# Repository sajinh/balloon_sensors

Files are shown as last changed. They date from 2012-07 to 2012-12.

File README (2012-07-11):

On the balloon we aim for data logging instead of real-time transmission. The
balloon is to be brought down periodically to collect data. Data is collected
using an onboard uLog.

We use BMP085 to measure absolute pressure. This also provides the temperature
value. BMP085 uses a Two Wire protocol for data transmission and operates
at 3.3V.  Analog Pin 5 is used for SCL and Analog Pin 4 for SDA.

We use HH10D to measure relative humidity. A Two Wire interface is needed
to read calibration coefficients from its onboard EEPROM. However we 
read it for once, record it in the sensor code, and never use the Two Wire
interface thereafter. The data is output as encoded frequency and output through
the middle pin.

uLog is a Serial Logger. Data is send through the TX line of the microcontroller

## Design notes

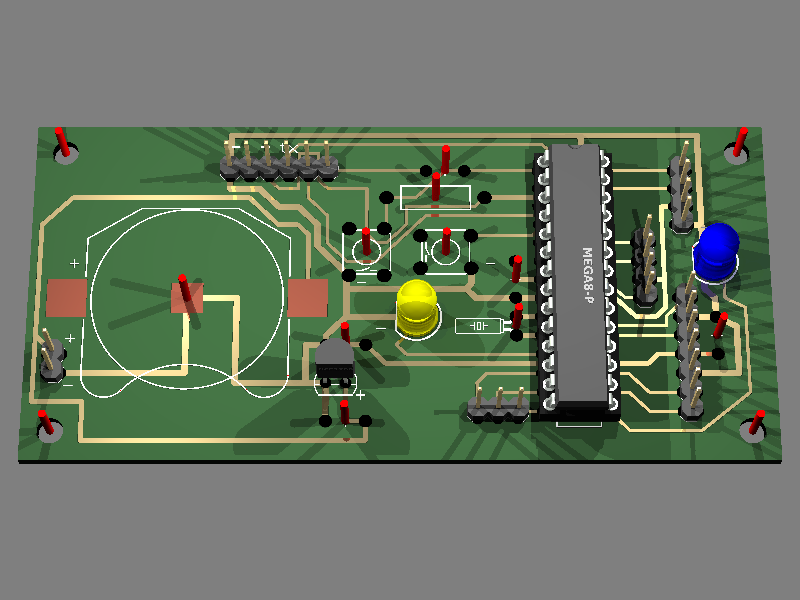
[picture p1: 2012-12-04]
Eagle/controller.png

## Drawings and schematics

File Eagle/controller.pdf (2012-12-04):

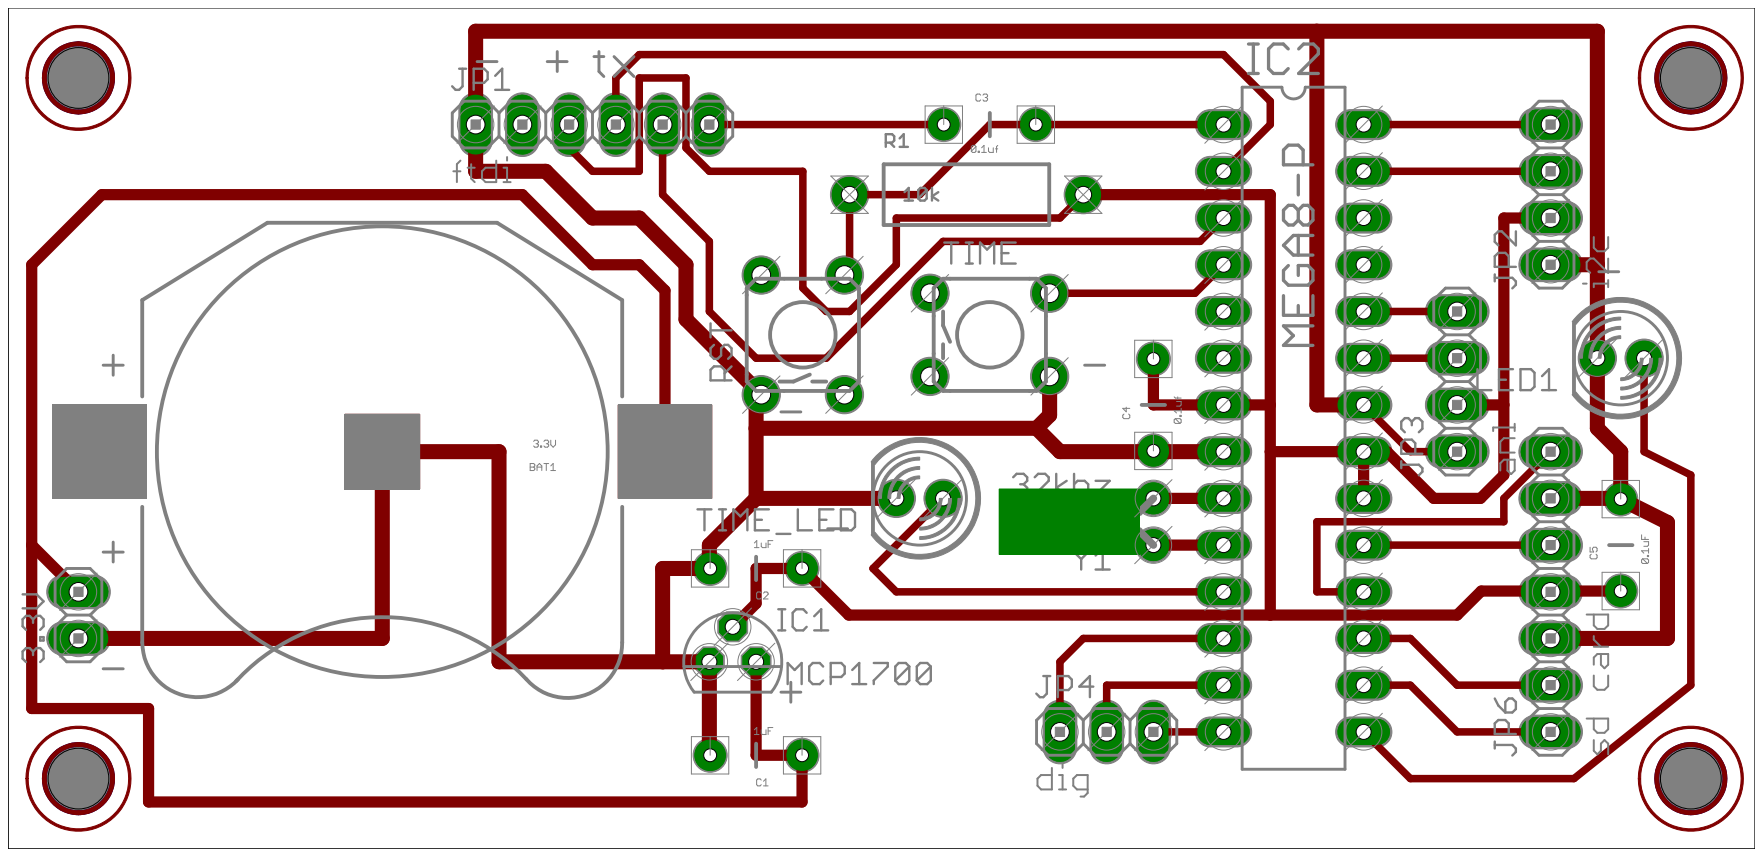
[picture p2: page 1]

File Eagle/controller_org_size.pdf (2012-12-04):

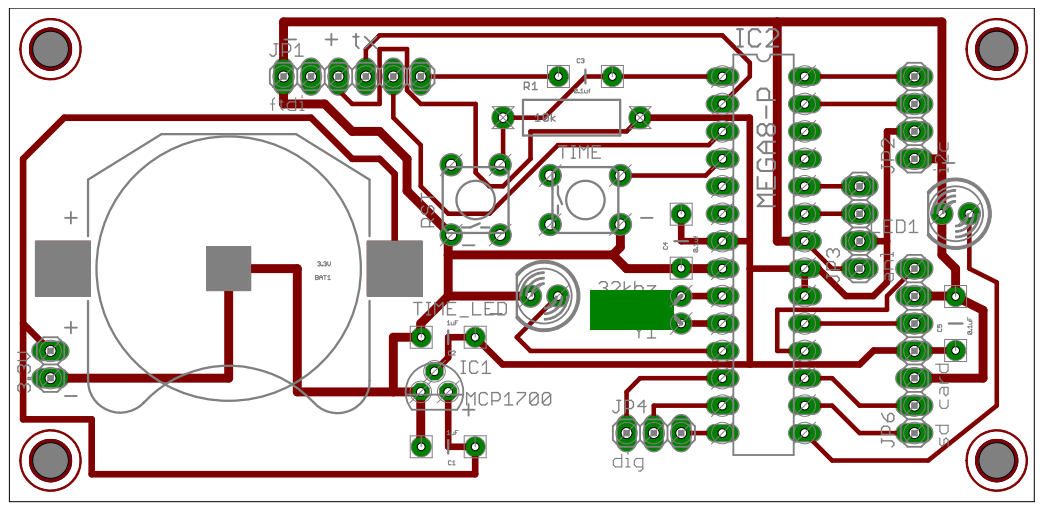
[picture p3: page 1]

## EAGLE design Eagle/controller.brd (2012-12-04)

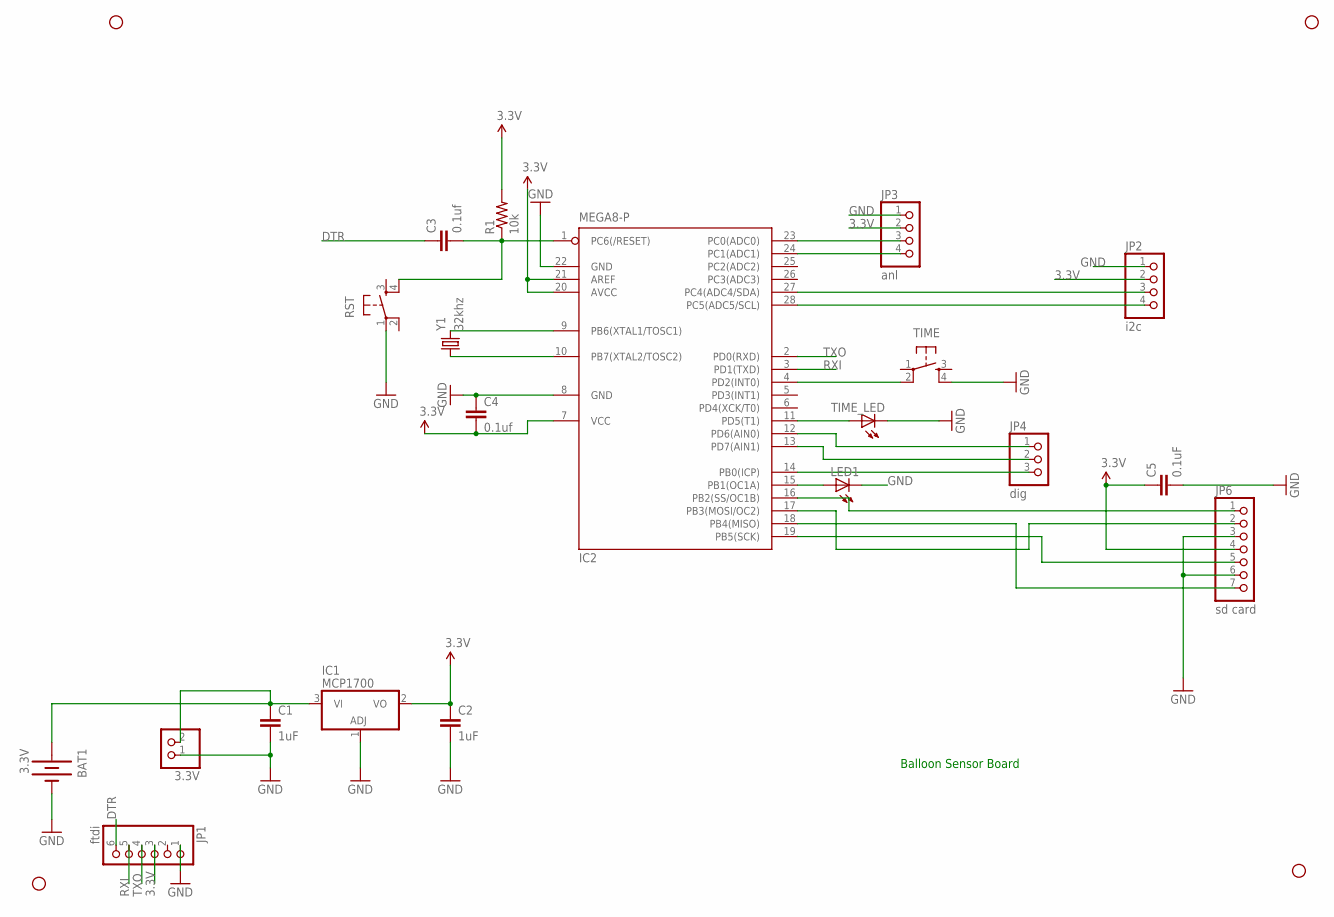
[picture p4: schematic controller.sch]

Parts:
3.3V: PINHD-1X2; 1X02
BAT1: 3.3V; BATTCON_245MM
C1, C2: 1uF; CAP-PTH-5MM
C3, C4: 0.1uf; CAP-PTH-5MM
C5: 0.1uF; CAP-PTH-5MM
IC1: MCP1700; TO92
IC2: MEGA8-P; DIL28-3
JP1: ftdi; 1X06
JP2: i2c; 1X04
JP3: anl; 1X04
JP4: dig; 1X03
JP6: sd card; 1X07
LED1: LED5MM
R1: 10k; AXIAL-0.5
RST: TAC_SWITCHPTH; TACTILE-PTH
STANDOFF1, STANDOFF2, STANDOFF3, STANDOFF4: STAND-OFF
TIME: TAC_SWITCHPTH; TACTILE-PTH
TIME_LED: LED5MM
Y1: 32khz; TC26H

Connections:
3.3V: C2.1, C4.2, C5.1, IC1.2 (VO), IC2.7 (VCC), IC2.20 (AVCC), IC2.21 (AREF), JP1.3, JP2.2, JP3.2, JP6.4, R1.P$2 (2)
+: 3.3V.2, BAT1.1 (+), C1.1, IC1.3 (VI)
DTR: C3.1, JP1.6
GND: 3.3V.1, BAT1.2 (-), C1.2, C2.2, C4.1, C5.2, IC1.1 (ADJ), IC2.8 (GND), IC2.22 (GND), JP1.1, JP2.1, JP3.1, JP6.3, JP6.6, LED1.K (C), RST.1, TIME.4, TIME_LED.K (C)
unnamed: C3.2, IC2.1 (PC6(/RESET)), R1.P$1 (1), RST.4
unnamed: IC2.15 (PB1(OC1A)), LED1.A
unnamed: IC2.28 (PC5(ADC5/SCL)), JP2.4
unnamed: IC2.9 (PB6(XTAL1/TOSC1)), Y1.2
unnamed: IC2.10 (PB7(XTAL2/TOSC2)), Y1.1
unnamed: IC2.14 (PB0(ICP)), JP4.3
unnamed: IC2.4 (PD2(INT0)), TIME.2
unnamed: IC2.13 (PD7(AIN1)), JP4.2
unnamed: IC2.27 (PC4(ADC4/SDA)), JP2.3
unnamed: IC2.24 (PC1(ADC1)), JP3.4
unnamed: IC2.23 (PC0(ADC0)), JP3.3
unnamed: IC2.12 (PD6(AIN0)), JP4.1
unnamed: IC2.11 (PD5(T1)), TIME_LED.A
unnamed: IC2.19 (PB5(SCK)), JP6.5
unnamed: IC2.18 (PB4(MISO)), JP6.7
unnamed: IC2.16 (PB2(SS/OC1B)), JP6.1
unnamed: IC2.17 (PB3(MOSI/OC2)), JP6.2
RXI: IC2.3 (PD1(TXD)), JP1.5
TXO: IC2.2 (PD0(RXD)), JP1.4

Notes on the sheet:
Balloon Sensor Board

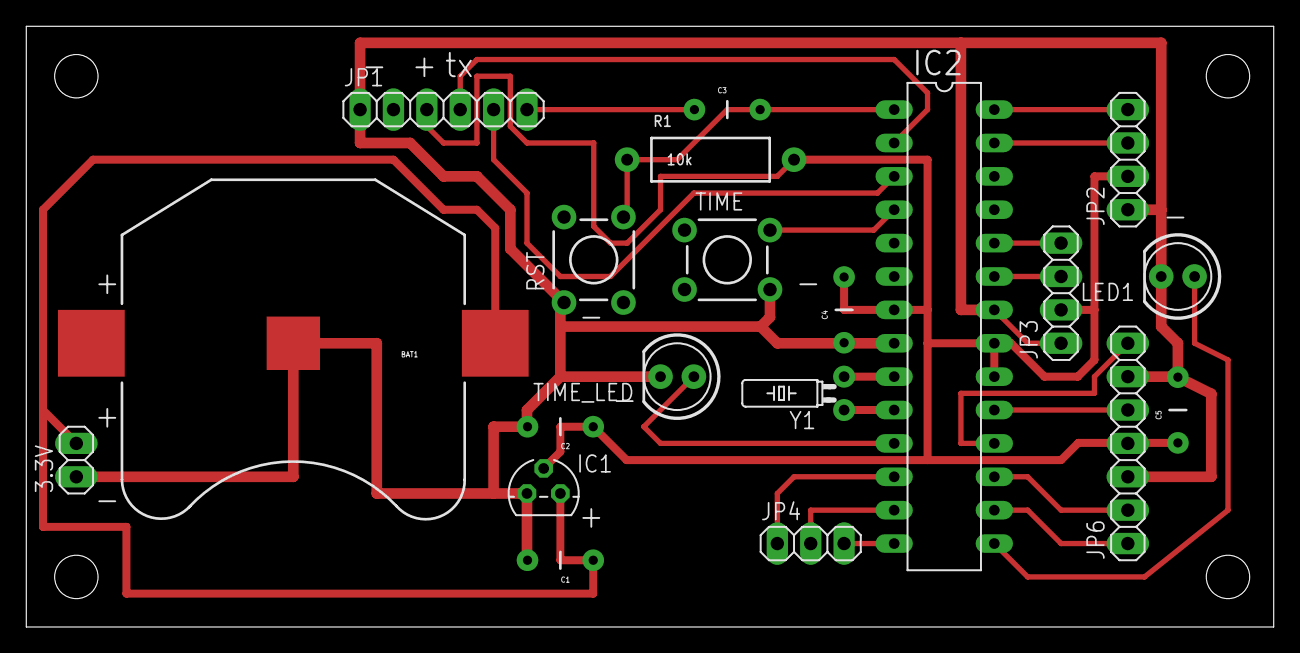
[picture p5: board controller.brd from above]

Board: 2 copper layers, 94.9 x 45.7 mm, 24 parts (0 on the bottom side), 23 nets.

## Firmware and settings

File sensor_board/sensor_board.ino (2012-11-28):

#include <Wire.h>
#include "FreqCounter.h" // Optional (not required by this code)
#include "HH10D2.h" 
#include "LowPower.h"
#include <SoftwareSerial.h>

using namespace std;
HH10D humid(384, 7688); //Using FreqCounter library
int count = 0;
#define BMP085_ADDRESS 0x77  // I2C address of BMP085
const unsigned char OSS = 0;  // Oversampling Setting
// Calibration values
int ac1;
int ac2;
int ac3;
unsigned int ac4;
unsigned int ac5;
unsigned int ac6;
int b1;
int b2;
int mb;
int mc;
int md;

// b5 is calculated in bmp085GetTemperature(...), this variable is also used in bmp085GetPressure(...)
// so ...Temperature(...) must be called before ...Pressure(...).
long b5;
float tempC;
float pressMB;
float rh;
int scount=0;
int tcount=0;
int sampling_secs=304;
int nwake_up=sampling_secs/8;

// These are for uLog
char buff[50];
int fileNumber = 1;
int statLED = 13;
int resetOpenLog = 4;

SoftwareSerial OpenLog(3, 2);

void setup(){
  //Serial.begin(9600);
  initialize_openLog();
  Wire.begin();
  bmp085Calibration();
  humid.setGateTime(500);
  wake_and_read();
  wake_and_read();
}

void loop()
{
  LowPower.powerSave(SLEEP_8S, ADC_OFF, BOD_OFF, TIMER2_OFF);
  if (tcount == 0) 
    {
      wake_and_read();
      log_sensor_values();
      //display_sensor_values();
    }
  tcount++;
  if (tcount > nwake_up) {tcount=0;}
}

void wake_and_read()
{
  readBMP085();
  readHH10D();
  
  //if (scount > 1) {display_sensor_values();}
 // if (scount < 2) { scount++;}
}


void display_sensor_values(void)
{
  Serial.println(nwake_up);
  Serial.print("Temperature : ");
  Serial.print(tempC);
  Serial.println(" C");
  
  Serial.print("Humidity : ");
  Serial.print(rh);
  Serial.println(" %");
  
  Serial.print("Pressure : ");
  Serial.print(pressMB);
  Serial.println(" mb");
  delay(500);
}

void log_sensor_values(void)
{
  OpenLog.println(nwake_up);
  OpenLog.print("Temperature : ");
  OpenLog.print(tempC);
  OpenLog.println(" C");
  
  OpenLog.print("Humidity : ");
  OpenLog.print(rh);
  OpenLog.println(" %");
  
  OpenLog.print("Pressure : ");
  OpenLog.print(pressMB);
  OpenLog.println(" mb");
  delay(500);
}

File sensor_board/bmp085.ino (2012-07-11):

void readBMP085(void)
{
  tempC = bmp085GetTemperature(bmp085ReadUT()); //MUST be called first
  pressMB = bmp085GetPressure(bmp085ReadUP())/100.0;
}


// Stores all of the bmp085's calibration values into global variables
// Calibration values are required to calculate temp and pressure
// This function should be called at the beginning of the program
void bmp085Calibration()
{
  ac1 = bmp085ReadInt(0xAA);
  ac2 = bmp085ReadInt(0xAC);
  ac3 = bmp085ReadInt(0xAE);
  ac4 = bmp085ReadInt(0xB0);
  ac5 = bmp085ReadInt(0xB2);
  ac6 = bmp085ReadInt(0xB4);
  b1 = bmp085ReadInt(0xB6);
  b2 = bmp085ReadInt(0xB8);
  mb = bmp085ReadInt(0xBA);
  mc = bmp085ReadInt(0xBC);
  md = bmp085ReadInt(0xBE);
}

// Calculate temperature in deg C
float bmp085GetTemperature(unsigned int ut){
  long x1, x2;

  x1 = (((long)ut - (long)ac6)*(long)ac5) >> 15;
  x2 = ((long)mc << 11)/(x1 + md);
  b5 = x1 + x2;

  float temp = ((b5 + 8)>>4);
  temp = temp /10;

  return temp;
}

// Calculate pressure given up
// calibration values must be known
// b5 is also required so bmp085GetTemperature(...) must be called first.
// Value returned will be pressure in units of Pa.
long bmp085GetPressure(unsigned long up){
  long x1, x2, x3, b3, b6, p;
  unsigned long b4, b7;

  b6 = b5 - 4000;
  // Calculate B3
  x1 = (b2 * (b6 * b6)>>12)>>11;
  x2 = (ac2 * b6)>>11;
  x3 = x1 + x2;
  b3 = (((((long)ac1)*4 + x3)<<OSS) + 2)>>2;

  // Calculate B4
  x1 = (ac3 * b6)>>13;
  x2 = (b1 * ((b6 * b6)>>12))>>16;
  x3 = ((x1 + x2) + 2)>>2;
  b4 = (ac4 * (unsigned long)(x3 + 32768))>>15;

  b7 = ((unsigned long)(up - b3) * (50000>>OSS));
  if (b7 < 0x80000000)
    p = (b7<<1)/b4;
  else
    p = (b7/b4)<<1;

  x1 = (p>>8) * (p>>8);
  x1 = (x1 * 3038)>>16;
  x2 = (-7357 * p)>>16;
  p += (x1 + x2 + 3791)>>4;

  long temp = p;
  return temp;
}

// Read 1 byte from the BMP085 at 'address'
char bmp085Read(unsigned char address)
{
  unsigned char data;

  Wire.beginTransmission(BMP085_ADDRESS);
  Wire.write(address);
  Wire.endTransmission();

  Wire.requestFrom(BMP085_ADDRESS, 1);
  while(!Wire.available())
    ;

  return Wire.read();
}

// Read 2 bytes from the BMP085
// First byte will be from 'address'
// Second byte will be from 'address'+1
int bmp085ReadInt(unsigned char address)
{
  unsigned char msb, lsb;

  Wire.beginTransmission(BMP085_ADDRESS);
  Wire.write(address);
  Wire.endTransmission();

  Wire.requestFrom(BMP085_ADDRESS, 2);
  while(Wire.available()<2)
    ;
  msb = Wire.read();
  lsb = Wire.read();

  return (int) msb<<8 | lsb;
}

// Read the uncompensated temperature value
unsigned int bmp085ReadUT(){
  unsigned int ut;

  // Write 0x2E into Register 0xF4
  // This requests a temperature reading
  Wire.beginTransmission(BMP085_ADDRESS);
  Wire.write(0xF4);
  Wire.write(0x2E);
  Wire.endTransmission();

  // Wait at least 4.5ms
  delay(5);

  // Read two bytes from registers 0xF6 and 0xF7
  ut = bmp085ReadInt(0xF6);
  return ut;
}

// Read the uncompensated pressure value
unsigned long bmp085ReadUP(){

  unsigned char msb, lsb, xlsb;
  unsigned long up = 0;

  // Write 0x34+(OSS<<6) into register 0xF4
  // Request a pressure reading w/ oversampling setting
  Wire.beginTransmission(BMP085_ADDRESS);
  Wire.write(0xF4);
  Wire.write(0x34 + (OSS<<6));
  Wire.endTransmission();

  // Wait for conversion, delay time dependent on OSS
  delay(2 + (3<<OSS));

  // Read register 0xF6 (MSB), 0xF7 (LSB), and 0xF8 (XLSB)
  msb = bmp085Read(0xF6);
  lsb = bmp085Read(0xF7);
  xlsb = bmp085Read(0xF8);

  up = (((unsigned long) msb << 16) | ((unsigned long) lsb << 8) | (unsigned long) xlsb) >> (8-OSS);

  return up;
}

void writeRegister(int deviceAddress, byte address, byte val) {
  Wire.beginTransmission(deviceAddress); // start transmission to device 
  Wire.write(address);       // send register address
  Wire.write(val);         // send value to write
  Wire.endTransmission();     // end transmission
}

int readRegister(int deviceAddress, byte address){

  int v;
  Wire.beginTransmission(deviceAddress);
  Wire.write(address); // register to read
  Wire.endTransmission();

  Wire.requestFrom(deviceAddress, 1); // read a byte

  while(!Wire.available()) {
    // waiting
  }

  v = Wire.read();
  return v;
}

float calcAltitude(float pressure){

  float A = pressure/101325;
  float B = 1/5.25588;
  float C = pow(A,B);
  C = 1 - C;
  C = C /0.0000225577;

  return C;
}

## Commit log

2012-11-28 eagle files
    [controller.sch]
2012-12-04 new Eagle files
    [controller.brd, controller.sch]

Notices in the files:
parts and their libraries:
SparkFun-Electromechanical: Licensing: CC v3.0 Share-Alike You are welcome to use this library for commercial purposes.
